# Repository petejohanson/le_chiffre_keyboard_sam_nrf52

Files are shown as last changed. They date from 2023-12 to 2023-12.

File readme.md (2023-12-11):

# DO NOT USE THIS YET

This is a fork of the awesome [Le Chiffre STM32 by Sporkus](https://github.com/sporkus/le_chiffre_keyboard_stm32/) refactored to
SAM L/D21 and a secondary nRF52805 BLE module that is COMPLETELY UNTESTED.

Don't print it, don't try it and ask why it doesn't work.

When it's ready and tested, this will be updated. Until then, just don't.

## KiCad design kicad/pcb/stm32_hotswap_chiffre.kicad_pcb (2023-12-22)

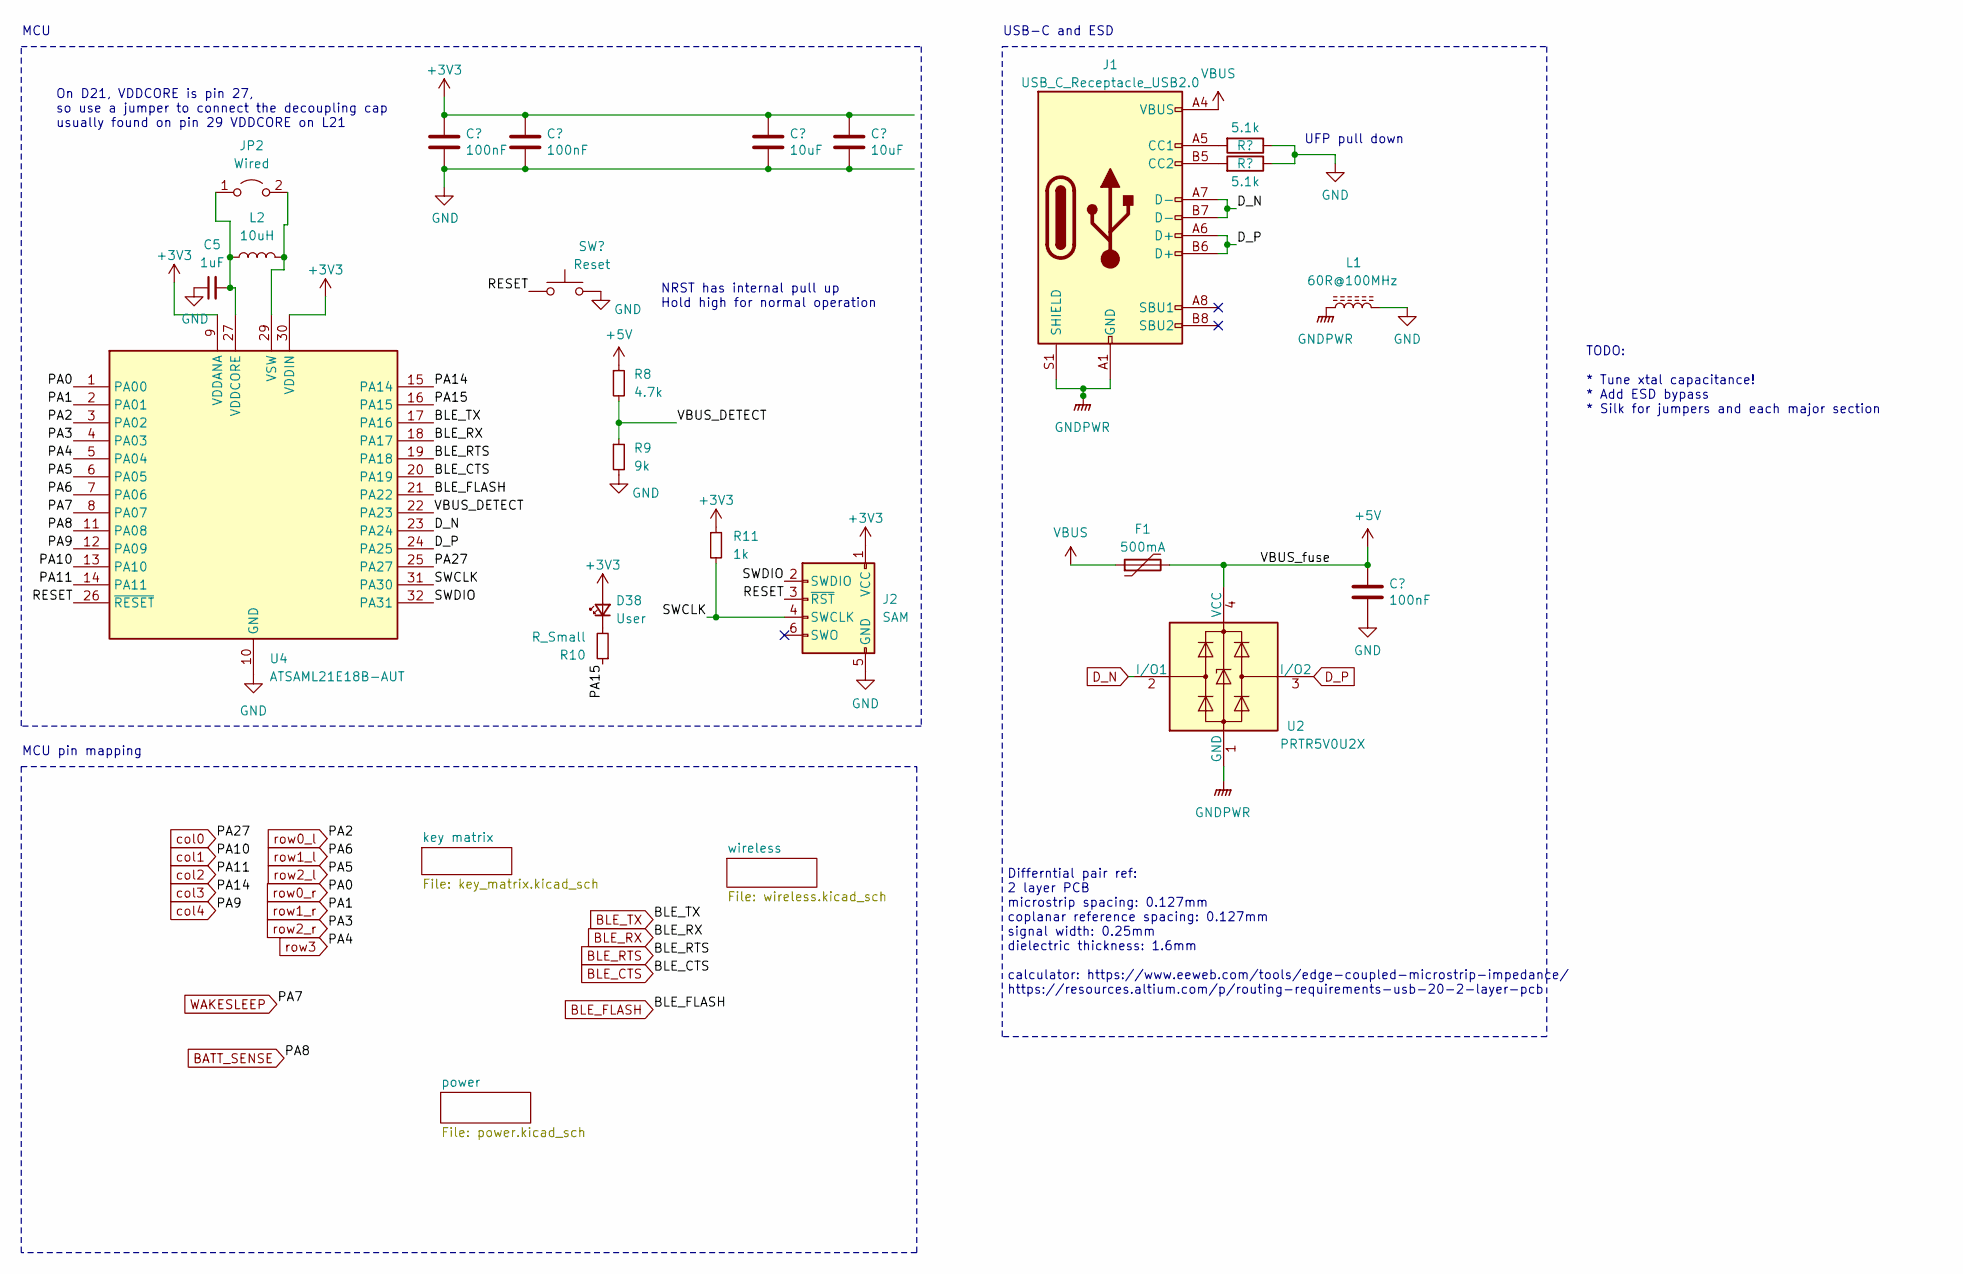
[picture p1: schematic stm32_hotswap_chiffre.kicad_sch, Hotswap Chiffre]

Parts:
C1, C2, C8: 100nF; C_0805_2012Metric; LCSC C38141
C3, C4: 10uF; C_0805_2012Metric; LCSC C17024
C5: 1uF; C_0805_2012Metric; LCSC C24123
D38: User; LED_0805_2012Metric; LCSC C84259
F1: 500mA; Fuse_1206_3216Metric; MPN BSMD1206-025-16V; LCSC C883119
J1: USB_C_Receptacle_USB2.0; USB_C_Receptacle_HRO_TYPE-C-31-M-12; MPN TYPE-C-31-M-12; JlcRotOffset 180
J2: SAM; CON_TC2030_outlined
JP2: Wired; SolderJumper-2_P1.3mm_Open_TrianglePad1.0x1.5mm
L1: 60R@100MHz; L_1206_3216Metric; MPN MLB3216-600P4A(f); LCSC C3033915
L2: 10uH; L_0805_2012Metric; LCSC C139245
R1, R2: 5.1k; R_0805_2012Metric; LCSC C118848
R8: 4.7k; R_0805_2012Metric; LCSC C228716
R9: 9k; R_0805_2012Metric; LCSC C2828721
R10: R_Small; R_0805_2012Metric; LCSC C2907256
R11: 1k; R_0805_2012Metric; LCSC C95781
SW37: Reset; SW_SPST_SKQG_WithoutStem; MPN SKQGABE010; LCSC C115351
U2: PRTR5V0U2X; SOT-143; MPN PRTR5V0U2X; LCSC C2827688
U4: ATSAML21E18B-AUT; TQFP-32_7x7mm_P0.8mm; MPN ATSAML21E18B-AUT; LCSC C2053723

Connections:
+5V: C8.1, F1.2, R8.1, U2.4 (VCC); also elsewhere on the board
/PA15: R10.1, U4.16 (PA15)
/RESET: J2.3 (~RST), SW37.1, U4.26 (~RESET)
/SWCLK: J2.4 (SWCLK), R11.2, U4.31 (PA30)
/SWDIO: J2.2 (SWDIO), U4.32 (PA31)
/VBUS_DETECT: R8.2, R9.1, U4.22 (PA23)
BATT_SENSE: U4.11 (PA08); also elsewhere on the board
BLE_CTS: U4.20 (PA19); also elsewhere on the board
BLE_FLASH: U4.21 (PA22); also elsewhere on the board
BLE_RTS: U4.19 (PA18); also elsewhere on the board
BLE_RX: U4.18 (PA17); also elsewhere on the board
BLE_TX: U4.17 (PA16); also elsewhere on the board
D_N: J1.A7 (D-), J1.B7 (D-), U2.2 (I/O1), U4.23 (PA24)
D_P: J1.A6 (D+), J1.B6 (D+), U2.3 (I/O2), U4.24 (PA25)
GNDPWR: J1.A1 (GND), J1.A12 (GND), J1.B1 (GND), J1.B12 (GND), J1.S1 (SHIELD), L1.1, U2.1 (GND)
unnamed: D38.1 (K), R10.2
unnamed: J1.A5 (CC1), R1.2
unnamed: J1.B5 (CC2), R2.2
unnamed: C5.2, JP2.1 (A), L2.1, U4.27 (VDDCORE)
unnamed: JP2.2 (B), L2.2, U4.29 (VSW)
VBUS: F1.1, J1.A4 (VBUS), J1.A9 (VBUS), J1.B4 (VBUS), J1.B9 (VBUS)
WAKESLEEP: U4.8 (PA07); also elsewhere on the board
col0: U4.25 (PA27); also elsewhere on the board
col1: U4.13 (PA10); also elsewhere on the board
col2: U4.14 (PA11); also elsewhere on the board
col3: U4.15 (PA14); also elsewhere on the board
col4: U4.12 (PA09); also elsewhere on the board
row0_l: U4.3 (PA02); also elsewhere on the board
row0_r: U4.1 (PA00); also elsewhere on the board
row1_l: U4.7 (PA06); also elsewhere on the board
row1_r: U4.2 (PA01); also elsewhere on the board
row2_l: U4.6 (PA05); also elsewhere on the board
row2_r: U4.4 (PA03); also elsewhere on the board
row3: U4.5 (PA04); also elsewhere on the board

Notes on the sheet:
On D21, VDDCORE is pin 27, so use a jumper to connect the decoupling cap usually found on pin 29 VDDCORE on L21
UFP pull down
MCU pin mapping
TODO: * Tune xtal capacitance! * Add ESD bypass * Silk for jumpers and each major section
MCU
USB-C and ESD
NRST has internal pull up Hold high for normal operation
Differntial pair ref: 2 layer PCB microstrip spacing: 0.127mm coplanar reference spacing: 0.127mm signal width: 0.25mm dielectric thickness: 1.6mm calculator: https://www.eeweb.com/tools/edge-coupled-microstrip-impedance/ https://resources.altium.com/p/routing-requirements-usb-20-2-layer-pcb

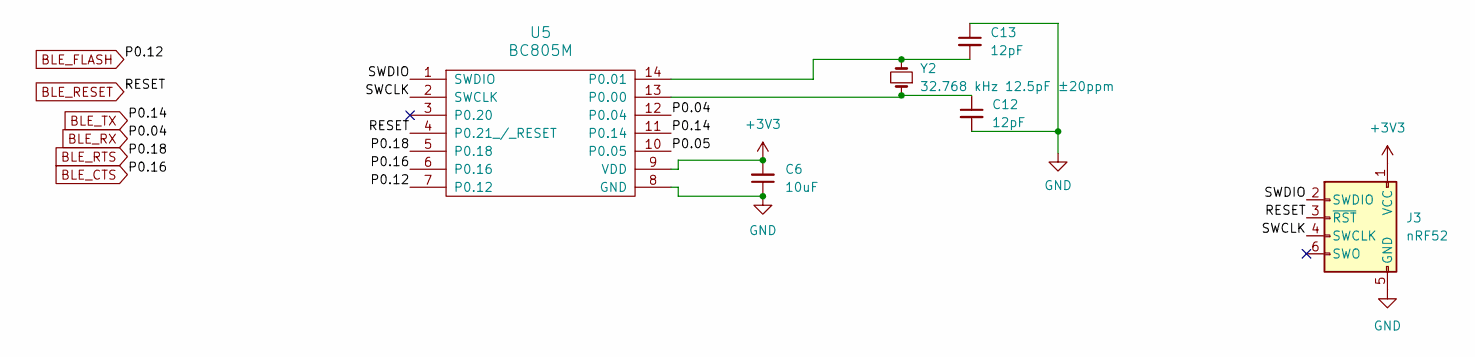
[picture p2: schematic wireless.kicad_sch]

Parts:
C6: 10uF; C_0805_2012Metric; LCSC C17024
C12, C13: 12pF; C_0805_2012Metric; LCSC C1792
J3: nRF52; CON_TC2030_outlined
U5: BC805M; MPN BC805M; LCSC C6751361
Y2: 32.768 kHz 12.5pF ±20ppm; Crystal_SMD_2012-2Pin_2.0x1.2mm_HandSoldering; LCSC C97603

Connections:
/wireless/P0.05: U5.10 (P0.05)
/wireless/SWCLK: J3.4 (SWCLK), U5.2 (SWCLK)
/wireless/SWDIO: J3.2 (SWDIO), U5.1 (SWDIO)
BLE_CTS: U5.6 (P0.16); also elsewhere on the board
BLE_FLASH: U5.7 (P0.12); also elsewhere on the board
BLE_RESET: J3.3 (~RST), U5.4 (P0.21_/_RESET)
BLE_RTS: U5.5 (P0.18); also elsewhere on the board
BLE_RX: U5.12 (P0.04); also elsewhere on the board
BLE_TX: U5.11 (P0.14); also elsewhere on the board
unnamed: C13.2, U5.14 (P0.01), Y2.2

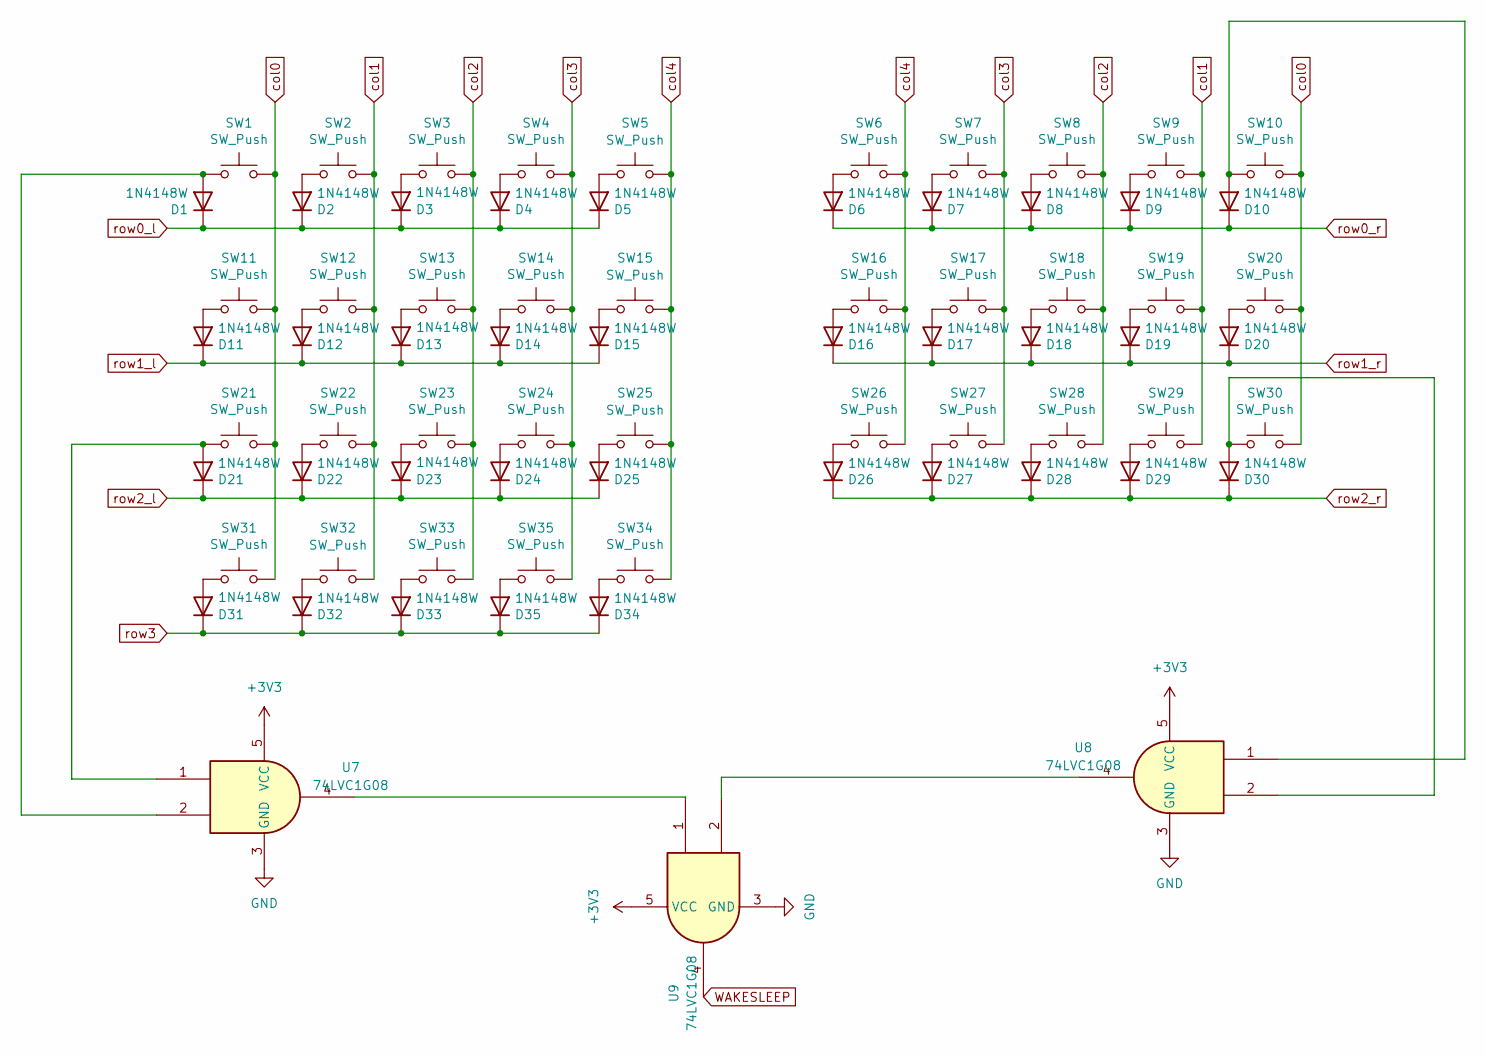
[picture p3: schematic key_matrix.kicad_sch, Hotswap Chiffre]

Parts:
D1, D2, D3, D4, D5, D11, D12, D13, D14, D15, D21, D22, D23, D24, D25, D31, D32: 1N4148W; D_SOD-123; MPN 1N4148W; JlcRotOffset 14
D6, D7, D8, D9, D10, D16, D17, D18, D19, D20, D26, D27, D28, D29, D30, D33, D34, D35: 1N4148W; D_SOD-123; MPN 1N4148W; JlcRotOffset -14
SW1, SW2, SW3, SW4, SW5, SW6, SW7, SW8, SW9, SW10, SW11, SW12, SW13, SW14, SW15, SW16, SW17, SW18, SW19, SW20, SW21, SW22, SW23, SW24, SW25, SW26, SW27, SW28, SW29, SW30, SW33: SW_Push; MX-Hotswap-Alps-1U
SW31, SW34: SW_Push; MX-Hotswap-Alps-1.25U
SW32, SW35: SW_Push; MX-Hotswap-Alps-2U
U7, U8, U9: 74LVC1G08; SOT-23-5_HandSoldering; MPN SN74LVC1G08DBVR; LCSC C7666

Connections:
unnamed: D1.2 (A), SW1.1, U7.2
unnamed: D2.2 (A), SW2.1
unnamed: D3.2 (A), SW3.1
unnamed: D4.2 (A), SW4.1
unnamed: D5.2 (A), SW5.1
unnamed: D6.2 (A), SW6.1
unnamed: D7.2 (A), SW7.1
unnamed: D8.2 (A), SW8.1
unnamed: D9.2 (A), SW9.1
unnamed: D10.2 (A), SW10.1, U8.1
unnamed: D11.2 (A), SW11.1
unnamed: D12.2 (A), SW12.1
unnamed: D13.2 (A), SW13.1
unnamed: D14.2 (A), SW14.1
unnamed: D15.2 (A), SW15.1
unnamed: D16.2 (A), SW16.1
unnamed: D17.2 (A), SW17.1
unnamed: D18.2 (A), SW18.1
unnamed: D19.2 (A), SW19.1
unnamed: D20.2 (A), SW20.1
unnamed: D21.2 (A), SW21.1, U7.1
unnamed: D22.2 (A), SW22.1
unnamed: D23.2 (A), SW23.1
unnamed: D24.2 (A), SW24.1
unnamed: D25.2 (A), SW25.1
unnamed: D26.2 (A), SW26.1
unnamed: D27.2 (A), SW27.1
unnamed: D28.2 (A), SW28.1
unnamed: D29.2 (A), SW29.1
unnamed: D30.2 (A), SW30.1, U8.2
unnamed: D31.2 (A), SW31.1
unnamed: D32.2 (A), SW32.1
unnamed: D33.2 (A), SW33.1
unnamed: D34.2 (A), SW34.1
unnamed: D35.2 (A), SW35.1
unnamed: U7.4, U9.1
unnamed: U8.4, U9.2
WAKESLEEP: U9.4; also elsewhere on the board
col0: SW1.2, SW10.2, SW11.2, SW20.2, SW21.2, SW30.2, SW31.2; also elsewhere on the board
col1: SW2.2, SW9.2, SW12.2, SW19.2, SW22.2, SW29.2, SW32.2; also elsewhere on the board
col2: SW3.2, SW8.2, SW13.2, SW18.2, SW23.2, SW28.2, SW33.2; also elsewhere on the board
col3: SW4.2, SW7.2, SW14.2, SW17.2, SW24.2, SW27.2, SW35.2; also elsewhere on the board
col4: SW5.2, SW6.2, SW15.2, SW16.2, SW25.2, SW26.2, SW34.2; also elsewhere on the board
row0_l: D1.1 (K), D2.1 (K), D3.1 (K), D4.1 (K), D5.1 (K); also elsewhere on the board
row0_r: D6.1 (K), D7.1 (K), D8.1 (K), D9.1 (K), D10.1 (K); also elsewhere on the board
row1_l: D11.1 (K), D12.1 (K), D13.1 (K), D14.1 (K), D15.1 (K); also elsewhere on the board
row1_r: D16.1 (K), D17.1 (K), D18.1 (K), D19.1 (K), D20.1 (K); also elsewhere on the board
row2_l: D21.1 (K), D22.1 (K), D23.1 (K), D24.1 (K), D25.1 (K); also elsewhere on the board
row2_r: D26.1 (K), D27.1 (K), D28.1 (K), D29.1 (K), D30.1 (K); also elsewhere on the board
row3: D31.1 (K), D32.1 (K), D33.1 (K), D34.1 (K), D35.1 (K); also elsewhere on the board

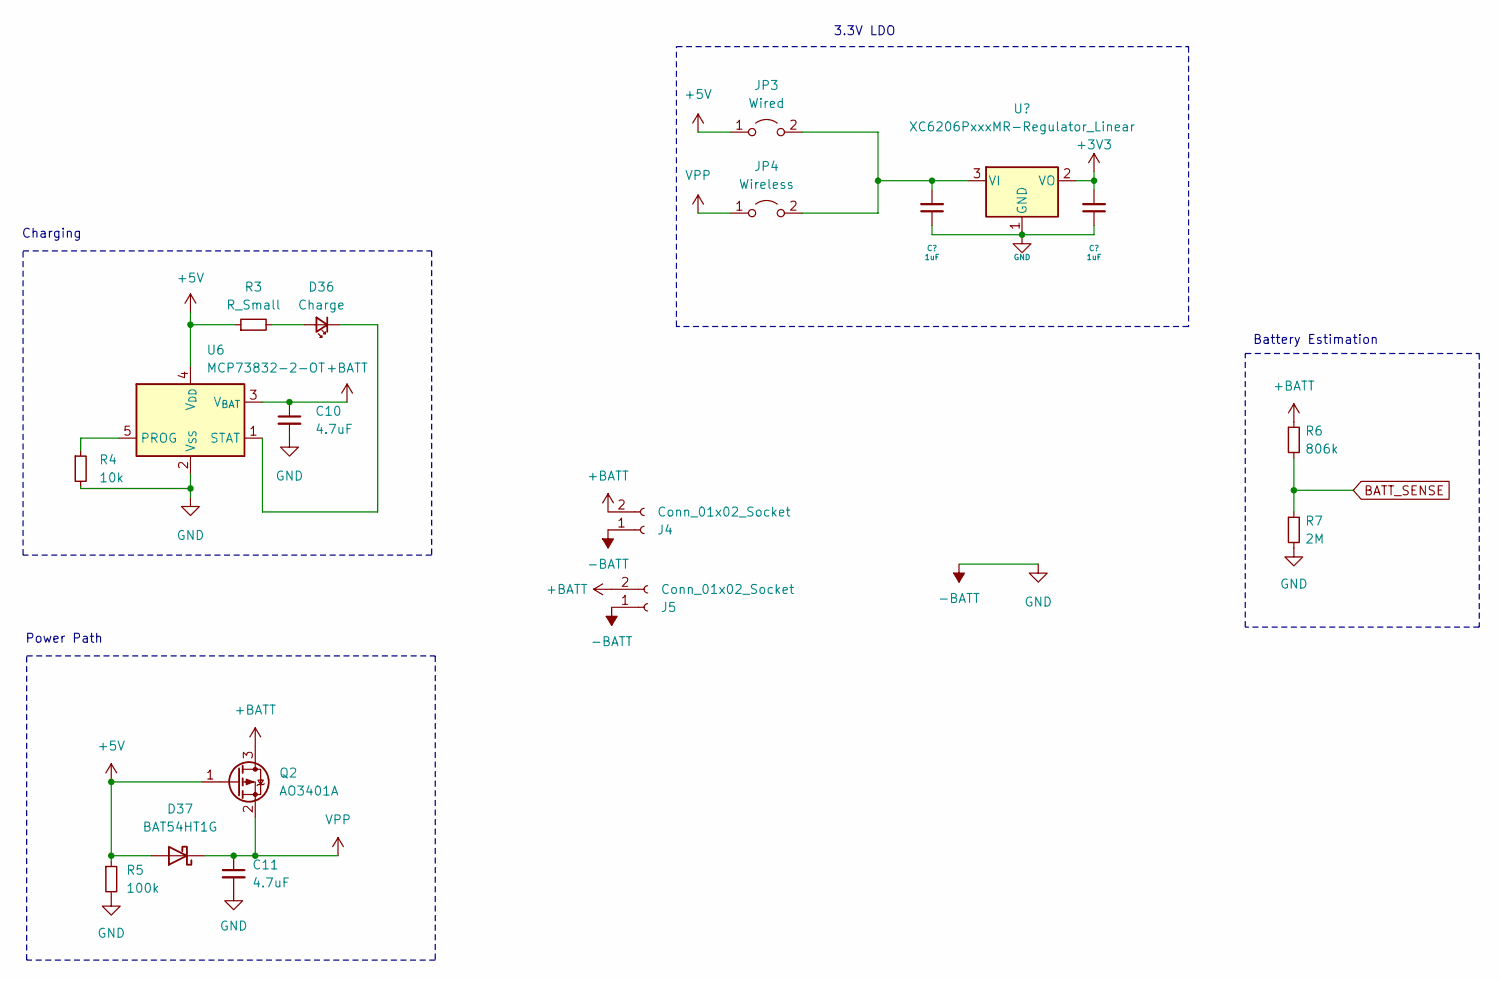
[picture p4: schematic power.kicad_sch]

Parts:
C10, C11: 4.7uF; C_0805_2012Metric; LCSC C1779
C12: 1uF; C_0805_2012Metric; LCSC C24123
D36: Charge; LED_0805_2012Metric; LCSC C2943978
D37: BAT54HT1G; D_SOD-323; MPN BAT54HT1G; LCSC C179609
J4: Conn_01x02_Socket; JST_SH_SM02B-SRSS-TB_1x02-1MP_P1.00mm_Horizontal; MPN SH-SM02B (SRSS)-TB
J5: Conn_01x02_Socket; PinHeader_1x02_P2.54mm_Vertical
JP3: Wired; SolderJumper-2_P1.3mm_Open_TrianglePad1.0x1.5mm
JP4: Wireless; SolderJumper-2_P1.3mm_Open_TrianglePad1.0x1.5mm
Q2: AO3401A; SOT-23; MPN AO3401A; LCSC C15127
R3: R_Small; R_0805_2012Metric; LCSC C2828866
R4: 10k; R_0805_2012Metric; LCSC C100047
R5: 100k; R_0805_2012Metric; LCSC C96346
R6: 806k; R_0805_2012Metric; LCSC C3016844
R7: 2M; R_0805_2012Metric; LCSC C228716
U3: XC6206PxxxMR-Regulator_Linear; SOT-23; MPN XC6206P332PR-G; LCSC C5446
U6: MCP73832-2-OT; SOT-23-5; MPN MCP73832-2-OT; LCSC C38066

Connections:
+5V: D37.2 (A), JP3.1 (A), Q2.1 (G), R3.1, R5.1, U6.4 (V_{DD}); also elsewhere on the board
+BATT: C10.1, J4.2, J5.2, Q2.3 (D), R6.1, U6.3 (V_{BAT})
BATT_SENSE: R6.2, R7.1; also elsewhere on the board
unnamed: D36.2 (A), R3.2
unnamed: D36.1 (K), U6.1 (STAT)
unnamed: R4.1, U6.5 (PROG)

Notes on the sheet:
Power Path
3.3V LDO
Battery Estimation
Charging

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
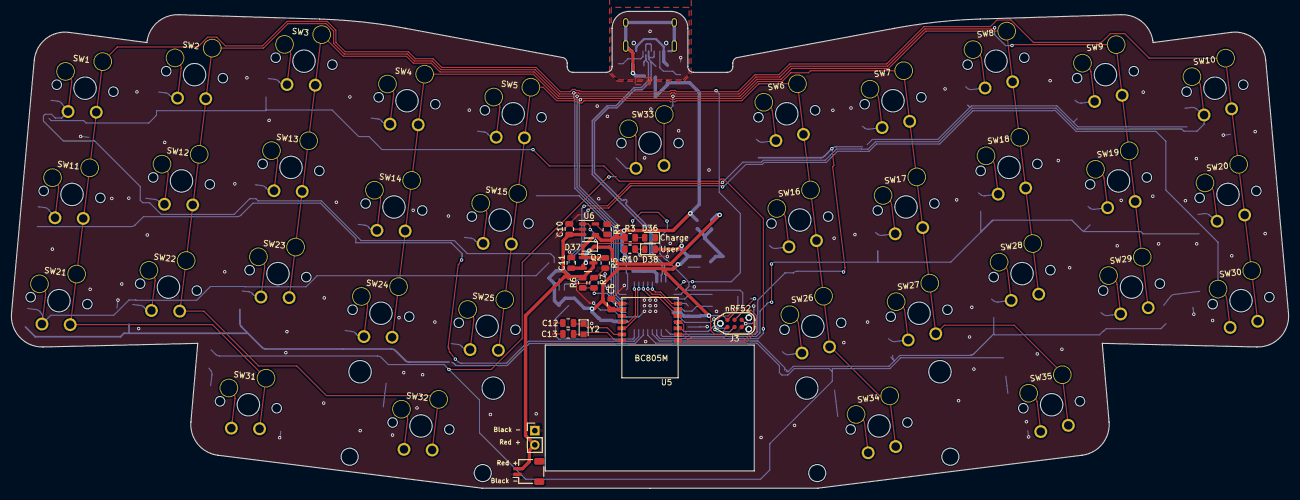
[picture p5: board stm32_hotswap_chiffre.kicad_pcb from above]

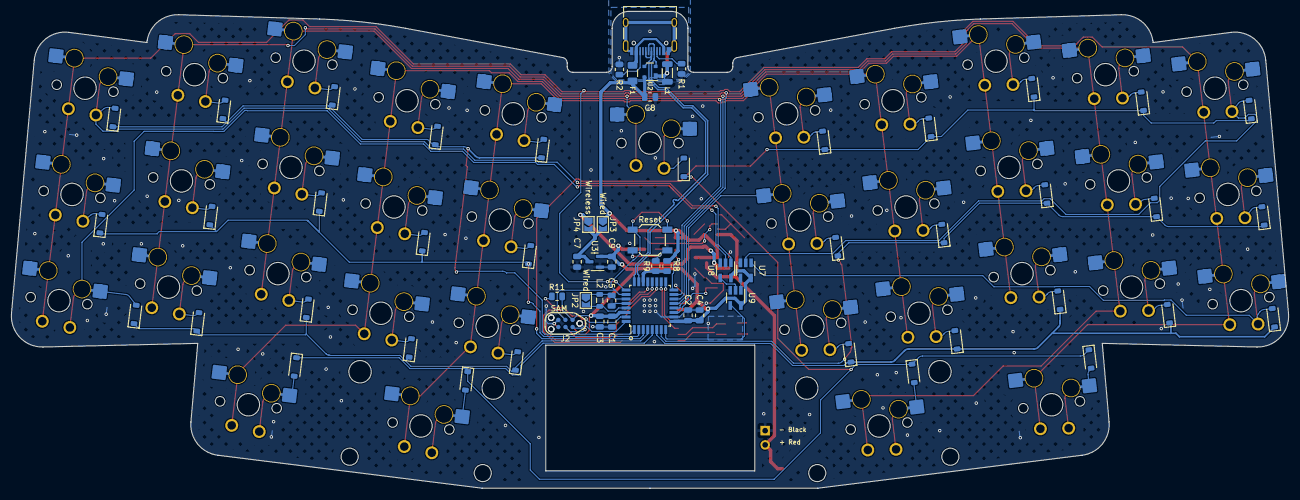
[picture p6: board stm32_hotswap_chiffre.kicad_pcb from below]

Board: 2 copper layers, 227.4 x 84.9 mm, 119 parts (63 on the bottom side), 84 nets.

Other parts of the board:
C7, C9: 1uF; C_0805_2012Metric

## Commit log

2023-12-12 Edge cut fixes.
    [stm32_hotswap_chiffre.kicad_pcb]
2023-12-19 Rework pins to use proper wake/interrupt pins for all matrix outputs, fix edge cuts.
    [stm32_hotswap_chiffre.kicad_pcb, stm32_hotswap_chiffre.kicad_sch]
2023-12-20 Minor cleanups of vias/traces and ERC happy.
    [stm32_hotswap_chiffre.kicad_pcb]
2023-12-20 BOM tweaks, switch to horizontal JST SH.
    [power.kicad_sch, stm32_hotswap_chiffre.kicad_pcb, stm32_hotswap_chiffre.kicad_sch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]
2023-12-22 More BOM tweaks.
    [key_matrix.kicad_sch, power.kicad_sch, stm32_hotswap_chiffre.kicad_pcb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]
